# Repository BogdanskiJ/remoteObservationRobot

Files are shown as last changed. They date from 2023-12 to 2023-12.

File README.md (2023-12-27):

# Remote Observation Robot

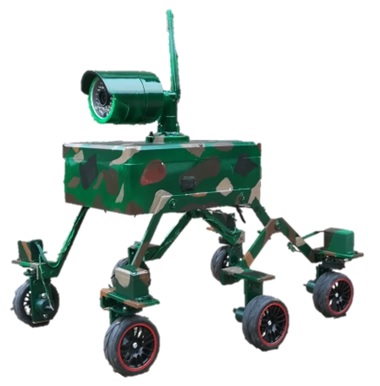
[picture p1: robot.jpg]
Robot


## Project description

This project presents a remote observation robot that was designed and built by me from scratch in 2018. This robot allows the user to conduct remote observations in hard-to-reach places, which is particularly useful in applications such as exploration of uninhabited areas, industrial inspections or environmental monitoring.

## Functions

### 1. HD camera

The robot is equipped with an HD camera that allows you to obtain high-quality images and recordings in real time. The user can conveniently view the image from the camera on their device.

### 2. Remote Control

The robot is remotely controlled using a dedicated application or web interface. Thanks to this, the user can control the robot's movement and camera orientation.

### 3. Systems 

- 2 x Arduino (Arduino Uno in my case)
- Wifi Camera
- Transmitter and receiver modules
- Motors and wheels for movement
- Distance sensors
- Battery or power source
- Computer or mobile device for remote control

### 4. Source Files

Source files allow you to recreate the robot using programs such as: Arduino IDE, 123D Design Autocad, EAGLE, Eclipse.

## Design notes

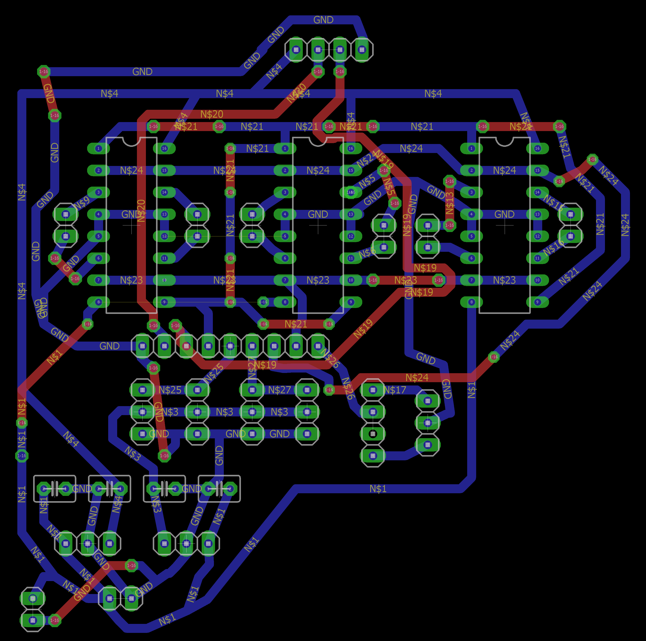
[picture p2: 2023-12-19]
receiverDiagramElectronicBoard.png

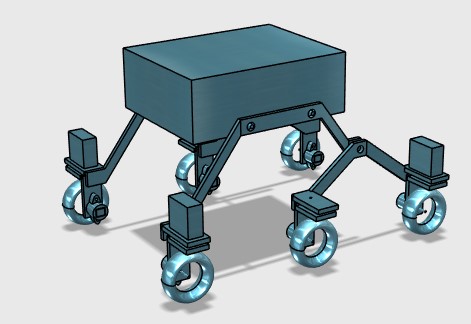
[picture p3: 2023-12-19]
robotMechanicProject.jpg

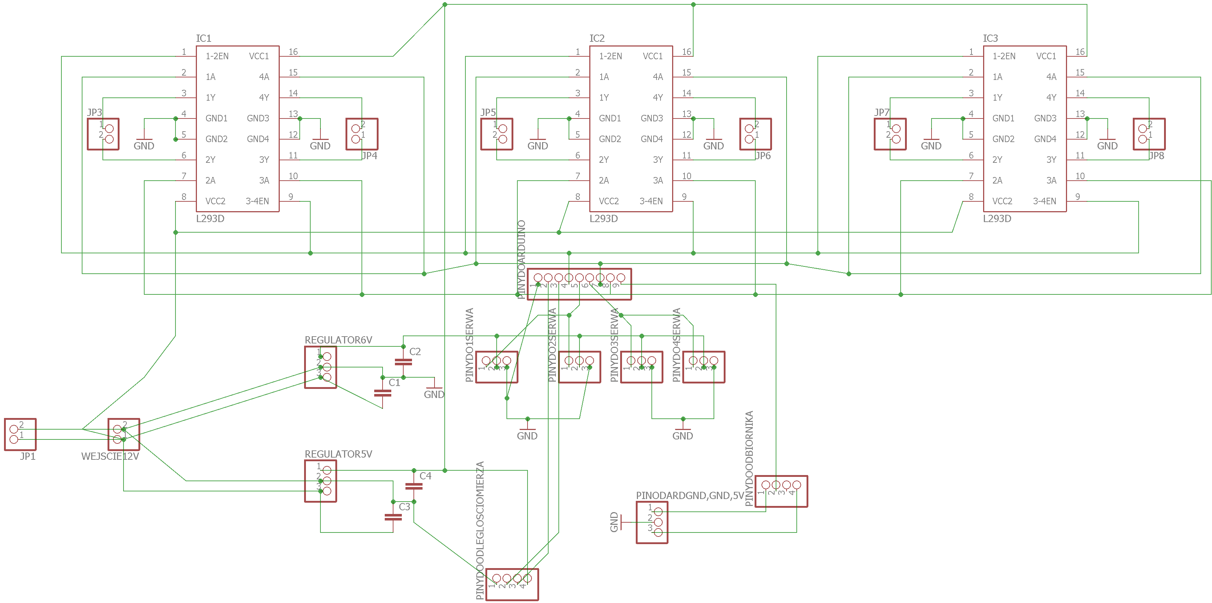
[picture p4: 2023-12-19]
receiverDiagram.png

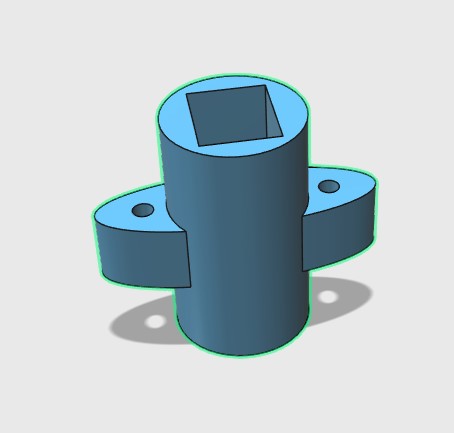
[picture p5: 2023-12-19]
motorCase.jpg

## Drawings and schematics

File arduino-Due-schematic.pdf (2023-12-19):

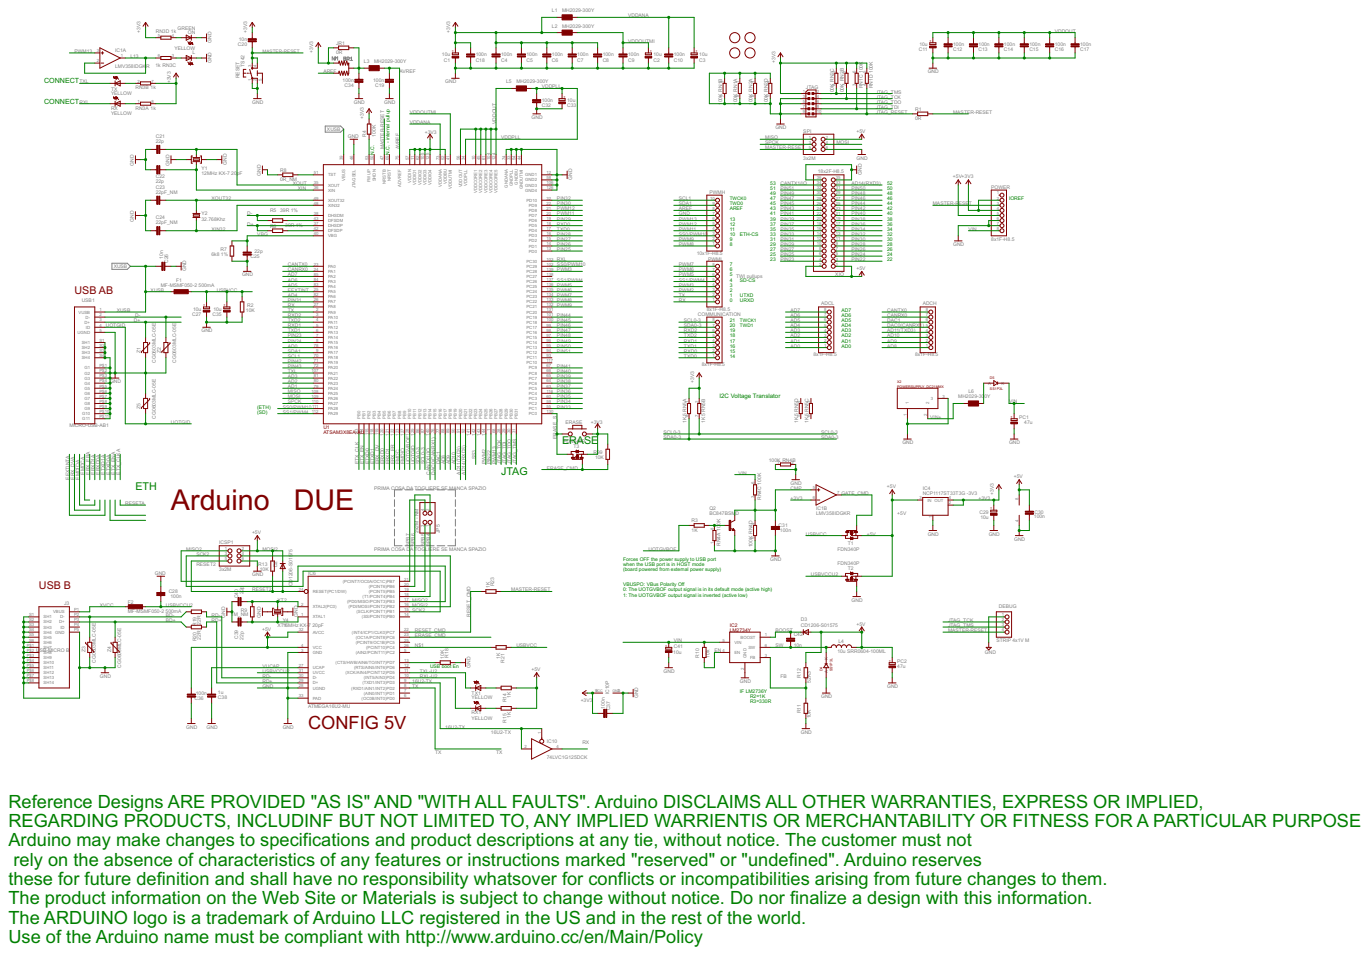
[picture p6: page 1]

PRIMA COSA DA TOGLIERE SE MANCA SPAZIO

SCK2 | 3 4

Forces OFF the power supply to USB port when the USB port is in HOST mode

(board powered from external power supply)

VBUSPO: VBus Polarity Off
0: The UOTGVBOF output signal is in its default mode (active high)
1: The UOTGVBOF output signal is inverted (active low)

Reference Designs ARE PROVIDED "AS IS" AND "WITH ALL FAULTS". Arduino DISCLAIMS ALL OTHER WARRANTIES, EXPRESS OR IMPLIED,
REGARDING PRODUCTS, INCLUDINF BUT NOT LIMITED TO, ANY IMPLIED WARRIENTIS OR MERCHANTABILITY OR FITNESS FOR A PARTICULAR PURPOSE
Arduino may make changes to specifications and product descriptions at any tie, without notice. The customer must not
rely on the absence of characteristics of any features or instructions marked "reserved" or "undefined". Arduino reserves
these for future definition and shall have no responsibility whatsover for conflicts or incompatibilities arising from future changes to them. The product information on the Web Site or Materials is subject to change without notice. Do nor finalize a design with this information. The ARDUINO logo is a trademark of Arduino LLC registered in the US and in the rest of the world. Use of the Arduino name must be compliant with http://www.arduino.cc/en/Main/Policy

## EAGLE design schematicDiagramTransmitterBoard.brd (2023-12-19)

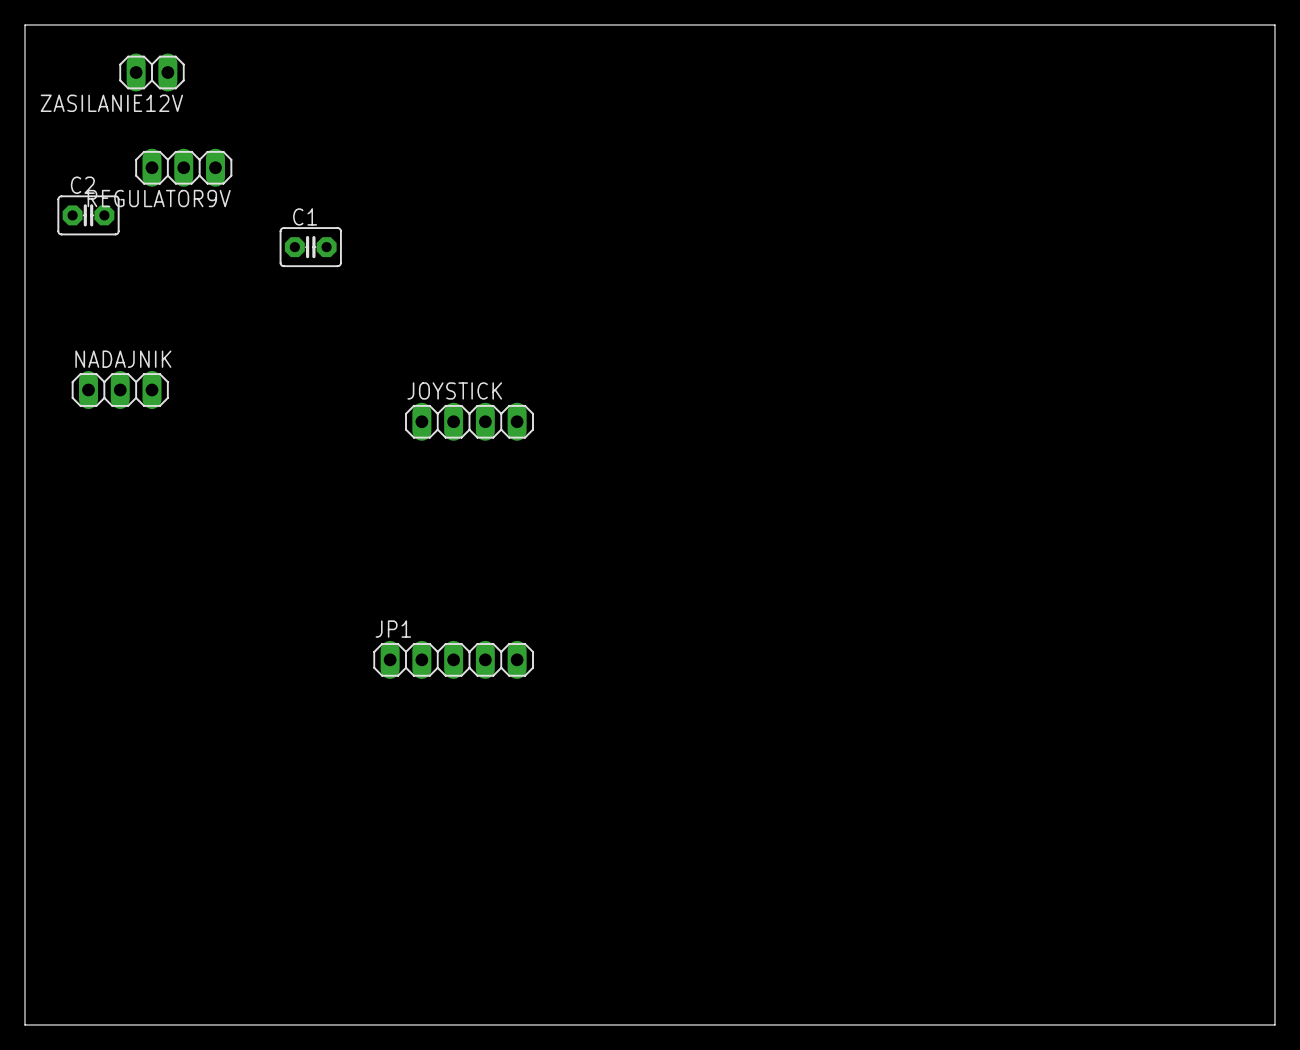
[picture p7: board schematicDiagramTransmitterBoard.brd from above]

Board: 2 copper layers, 100.0 x 80.0 mm, 7 parts (0 on the bottom side), 8 nets, no tracks yet.

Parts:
C1, C2: C2.5-3
JOYSTICK: 1X04
JP1: 1X05
NADAJNIK: 1X03
REGULATOR9V: 1X03
ZASILANIE12V: 1X02

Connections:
unnamed: C1.2, C2.1, NADAJNIK.1, REGULATOR9V.2, ZASILANIE12V.1
unnamed: C2.2, REGULATOR9V.3, ZASILANIE12V.2
unnamed: JOYSTICK.1, JP1.5
unnamed: JOYSTICK.2, JP1.4
unnamed: JOYSTICK.3, JP1.3
unnamed: JOYSTICK.4, JP1.2
unnamed: JP1.1, NADAJNIK.3
unnamed: C1.1, NADAJNIK.2, REGULATOR9V.1

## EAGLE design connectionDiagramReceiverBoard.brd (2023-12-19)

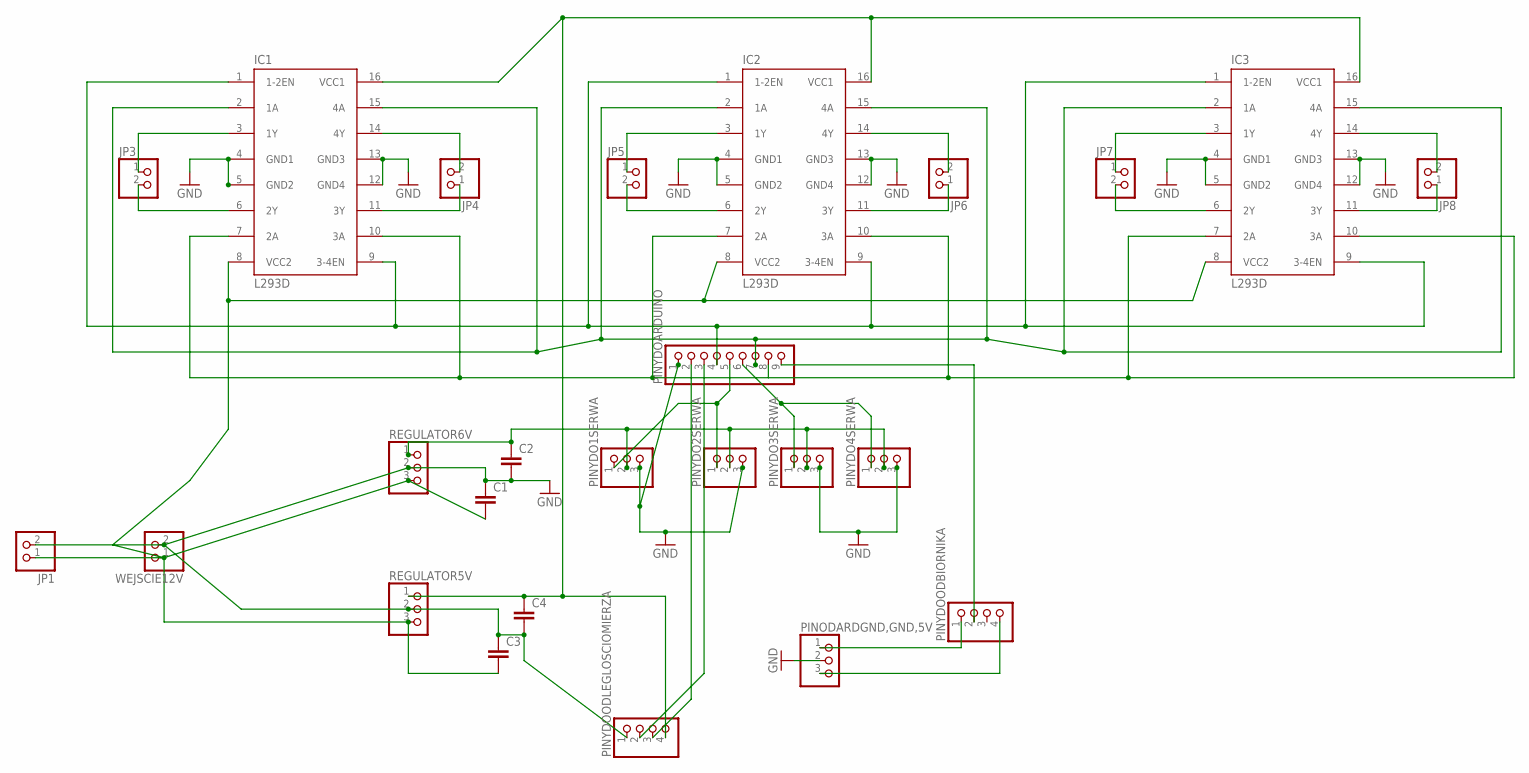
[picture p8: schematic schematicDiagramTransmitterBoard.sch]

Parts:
C1, C2, C3, C4: C2,5-3; C2.5-3
IC1, IC2, IC3: L293D; DIL16
JP1, JP3, JP4, JP5, JP6, JP7, JP8: PINHD-1X2; 1X02
PINODARDGND,GND,5V: PINHD-1X3; 1X03
PINYDO1SERWA, PINYDO2SERWA, PINYDO3SERWA, PINYDO4SERWA: PINHD-1X3; 1X03
PINYDOARDUINO: PINHD-1X9; 1X09
PINYDOODBIORNIKA: PINHD-1X4; 1X04
PINYDOODLEGLOSCIOMIERZA: PINHD-1X4; 1X04
REGULATOR5V, REGULATOR6V: PINHD-1X3; 1X03
WEJSCIE12V: PINHD-1X2; 1X02

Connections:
GND: C1.1, C2.2, C3.1, C4.2, IC1.4 (GND1), IC1.5 (GND2), IC1.12 (GND4), IC1.13 (GND3), IC2.4 (GND1), IC2.5 (GND2), IC2.12 (GND4), IC2.13 (GND3), IC3.4 (GND1), IC3.5 (GND2), IC3.12 (GND4), IC3.13 (GND3), JP1.2, PINODARDGND,GND,5V.2, PINYDO1SERWA.3, PINYDO2SERWA.3, PINYDO3SERWA.3, PINYDO4SERWA.3, PINYDOARDUINO.1, PINYDOODLEGLOSCIOMIERZA.1, REGULATOR5V.2, REGULATOR6V.2, WEJSCIE12V.2
unnamed: C1.2, C3.2, IC1.8 (VCC2), IC2.8 (VCC2), IC3.8 (VCC2), JP1.1, REGULATOR5V.3, REGULATOR6V.3, WEJSCIE12V.1
unnamed: C2.1, PINYDO1SERWA.2, PINYDO2SERWA.2, PINYDO3SERWA.2, PINYDO4SERWA.2, REGULATOR6V.1
unnamed: C4.1, IC1.16 (VCC1), IC2.16 (VCC1), IC3.16 (VCC1), PINYDOODLEGLOSCIOMIERZA.4, REGULATOR5V.1
unnamed: IC1.14 (4Y), JP4.2
unnamed: IC1.11 (3Y), JP4.1
unnamed: IC1.6 (2Y), JP3.2
unnamed: IC1.3 (1Y), JP3.1
unnamed: IC2.3 (1Y), JP5.1
unnamed: IC2.6 (2Y), JP5.2
unnamed: IC2.14 (4Y), JP6.2
unnamed: IC2.11 (3Y), JP6.1
unnamed: IC3.3 (1Y), JP7.1
unnamed: IC3.6 (2Y), JP7.2
unnamed: IC3.14 (4Y), JP8.2
unnamed: IC3.11 (3Y), JP8.1
unnamed: PINODARDGND,GND,5V.1, PINYDOODBIORNIKA.1
unnamed: PINODARDGND,GND,5V.3, PINYDOODBIORNIKA.4
unnamed: PINYDOARDUINO.3, PINYDOODLEGLOSCIOMIERZA.2
unnamed: PINYDOARDUINO.2, PINYDOODLEGLOSCIOMIERZA.3
unnamed: IC1.1 (1-2EN), IC1.9 (3-4EN), IC2.1 (1-2EN), IC2.9 (3-4EN), IC3.1 (1-2EN), IC3.9 (3-4EN), PINYDOARDUINO.4
unnamed: IC1.7 (2A), IC1.10 (3A), IC2.7 (2A), IC2.10 (3A), IC3.7 (2A), IC3.10 (3A), PINYDOARDUINO.8
unnamed: IC1.2 (1A), IC1.15 (4A), IC2.2 (1A), IC2.15 (4A), IC3.2 (1A), IC3.15 (4A), PINYDOARDUINO.7
unnamed: PINYDO1SERWA.1, PINYDO2SERWA.1, PINYDOARDUINO.5
unnamed: PINYDOARDUINO.9, PINYDOODBIORNIKA.2
unnamed: PINYDO3SERWA.1, PINYDO4SERWA.1, PINYDOARDUINO.6

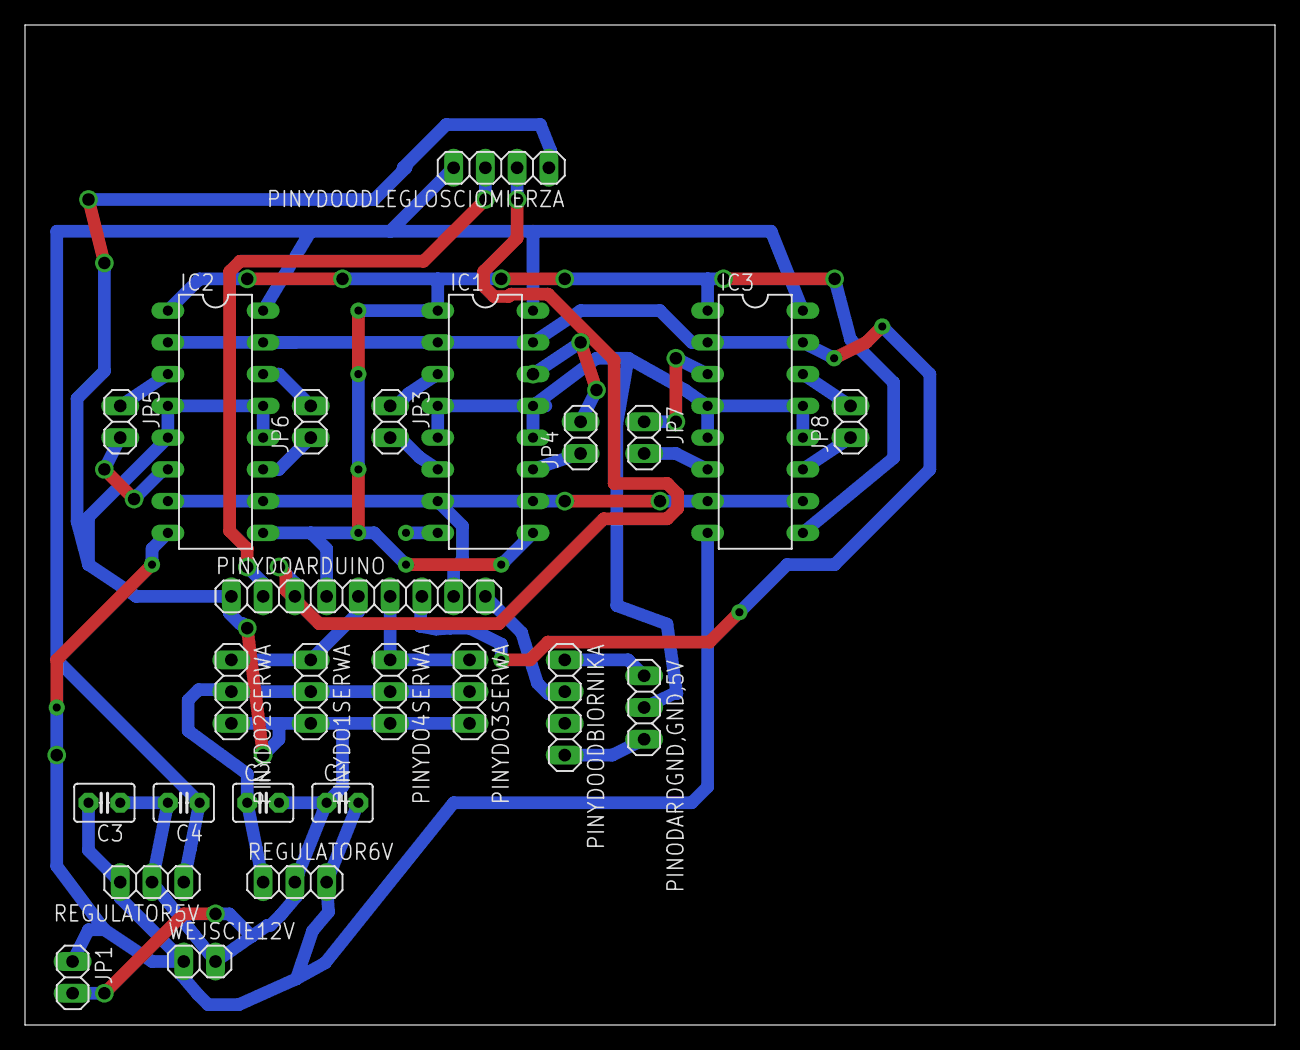
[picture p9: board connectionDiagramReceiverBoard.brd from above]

Board: 2 copper layers, 100.0 x 80.0 mm, 25 parts (0 on the bottom side), 26 nets.

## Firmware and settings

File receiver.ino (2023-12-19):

#include <SoftwareServo.h> 
#include <VirtualWire.h> 

#define odbior 3 
#define TRIG 12
#define ECHO 13
#define silnikpwm 11
#define silnik1 4
#define silnik2 7
#define servopwm1 10
#define servopwm2 9

SoftwareServo mojeservo1;
SoftwareServo mojeservo2;
int odczyt1; 
int odczyt2;
int a=0;
int licz=1;
unsigned long czas;
float odleglosc;

void setup()
{
    pinMode(silnikpwm,OUTPUT); 
    pinMode(silnik2, OUTPUT); 
    pinMode(silnik1, OUTPUT);
    pinMode(servopwm1, OUTPUT); 
    pinMode(servopwm2, OUTPUT); 
    pinMode(TRIG, OUTPUT); 
    pinMode(ECHO, INPUT);
    mojeservo1.attach(servopwm1); 
    mojeservo2.attach(servopwm2); 
    Serial.begin(9600); 
    vw_set_rx_pin(odbior); 
    vw_setup(2000);   
    vw_rx_start(); 
}

void loop()
{
    uint8_t buf[VW_MAX_MESSAGE_LEN]; 
    uint8_t buflen = VW_MAX_MESSAGE_LEN;
    int i,last;
    String odczytX1, odczytY1;
    if  (vw_get_message(buf, &buflen))
    {
       for  (i = 0; i < buflen; i++) 
       {
          if  (char(buf[i]) != '$')
              {
                odczytY1+=char(buf[i]);
              }
          else
              {
               i++;
               last = i; 
               break;
              } 
       }
       for  (i = last; i < buflen; i++) 
       {
          if  (char(buf[i]) != '$')
             { 
              odczytX1+=char(buf[i]);
             }
          else 
          break; 
       } 
        int odczytX = odczytX1.toInt();
        int odczytY = odczytY1.toInt();
        odczyt2=odczytX;
        odczyt1=odczytY;
    }
    
  licz=licz+1;
  if  (licz==200)
  {
    pomiar();
    if  (odleglosc<10.00)
    {
      stopp();
      delay(500);
      tyl();
      delay(500);
    }
  }

  if  (odczyt1>600) 
  {
     przod();
  }
  if  (odczyt1<450)
  {
     tyl();
  }
  if  (odczyt1<600 && odczyt1>500)
  {
     stopp();
  }
  if  (odczyt2>600)
  {
    prawo();
  }
  if  (odczyt2<450)
  {
    lewo();
  }
  if  (odczyt2>450 && odczyt2<600)
  {
    stopservo();
  }
}

void przod() 
{
  int sterY;
  sterY=map(odczyt1,600,1025,0,255);
  a=sterY;
  digitalWrite(silnik1,LOW);
  digitalWrite(silnik2,HIGH);
  analogWrite(silnikpwm,a);
}
void tyl()
{
  int sterY;
  sterY=map(odczyt1,450,0,0,255);
  a=sterY;
  digitalWrite(silnik1,HIGH);
  digitalWrite(silnik2,LOW);
  analogWrite(silnikpwm,a);
}
void stopp()
{
  digitalWrite(silnik1,LOW);
  digitalWrite(silnik2,LOW);
  analogWrite(silnikpwm,0);
}
void prawo()
{
  int pozservo1;
  int pozservo2;
  pozservo1=map(odczyt2,600,1025,100,180);
  pozservo2=180-pozservo1;
  mojeservo1.write(pozservo1);
  mojeservo2.write(pozservo2);
  SoftwareServo::refresh();
}
void lewo()
{
  int pozservo1;
  int pozservo2;
  pozservo1=map(odczyt2,0,450,0,80);
  pozservo2=180-pozservo1;
  mojeservo1.write(pozservo1);
  mojeservo2.write(pozservo2);
  SoftwareServo::refresh();
}
void stopservo()
{
  int pozservo1;
  pozservo1=90;
  mojeservo1.write(pozservo1);
  mojeservo2.write(pozservo1);
  SoftwareServo::refresh();
}
float pomiar() 
{
  digitalWrite(TRIG,HIGH);
  delayMicroseconds(10);
  digitalWrite(TRIG,LOW);
  czas = pulseIn(ECHO,HIGH);
  odleglosc = czas/58.00;
  licz=1;
  if(odleglosc>100)
  {
    odleglosc=100;
  }
  return odleglosc;
}

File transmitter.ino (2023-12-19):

#include <VirtualWire.h>
#define transmit_pin 8 
int sec = 1;
int odczytY=0;
int odczytX=0;
String   toSend="";
void setup()
{
  Serial.begin(9600);
  vw_set_tx_pin(transmit_pin);
  vw_setup(2000);
}
void loop()
{
  odczytY=analogRead(A0);
  odczytX=analogRead(A1);
  toSend= String(odczytX, DEC) + "$" + String(odczytY, DEC) + "$";
  char msg[23]; // tworzymy tablicę typu char
  toSend.toCharArray(msg, toSend.length() + 1);
  vw_send((uint8_t *)msg, strlen(msg));
  vw_wait_tx(); 
  delay(10);
}
